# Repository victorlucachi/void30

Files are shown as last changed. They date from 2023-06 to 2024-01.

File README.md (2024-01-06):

# VOID30
*A 30% handwired ortholinear keyboard*

VOID30

The VOID30 is a 3d printed, handwired, 30% ortholinear keyboard running QMK Firmware on a Pro Micro controller.

I suggest printing the case using a 0.4 mm nozzle, supports are not needed for any of the parts.

You might want/need to use small dabs of hot glue to secure the switches in the plate depending on how well calibrated your printer is (if you're generous with it, it will add to the weight of the keyboard and it might change the feel of it).

Dont overtighten the screws as the posts could break off and the threads might get stripped.

# Handwiring guide

I've also put together a pretty visual handwiring guide for the VOID9, that you can browse over [here](https://victorlucachi.ro/journal/void9-wiring-guide/).

|  	|  	|  	|
|---|---|---|

# Bill Of Materials

* 30 x diodes ([tme.eu](https://www.tme.eu/ro/en/details/1n4148-dio/tht-universal-diodes/diotec-semiconductor/1n4148/)/[aliexpress](https://www.aliexpress.com/item/32729204179.html))
* 30 x Cherry MX style mechanical switches
* 30 x keycaps of choice
* 1 x Pro Micro ([aliexpress](https://www.aliexpress.com/item/32902569443.html))
* 24 AWG (0.2 mm2) wire
* 4 x 8mm bumpons

### Redux
* 8 x M2x3x3.5 OD heat inserts ([aliexpress](https://www.aliexpress.com/item/4000585933306.html?spm=a2g0o.order_list.order_list_main.33.21ef1802vdSNrS))
* 4 x M2x10 Allen head screws ([aliexpress](https://www.aliexpress.com/item/32966941844.html?spm=a2g0o.order_detail.order_detail_item.9.722ff19cyjrixq))
* 4 x M2x6 Countersunk screws ([aliexpress](https://www.aliexpress.com/item/32968097507.html?spm=a2g0o.order_list.order_list_main.32.21ef1802vdSNrS))

### V1
* 4 x M3x10 countersunk screws that go through the top case ([tme.eu](https://www.tme.eu/ro/en/details/b3x10_bn661/bolts/bossard/1250752/)/[aliexpress](https://www.aliexpress.com/item/32968097507.html))
* 4 x M3x10 allen head screws ([tme.eu](https://www.tme.eu/ro/en/details/m3x10_d912-a2/bolts/kraftberg/)/[aliexpress](https://www.aliexpress.com/item/32966941844.html))
* hotglue

# Pin assignment

    ROW0    ROW1    ROW2
    F6      F7      B1

    COL0    COL1    COL2    COL3    COL4    COL5    COL6    COL7    COL8    COL9
    F5      F4      B5      B4      E6      D7      C6      D4      D0      D1

# QMK Vial Fork

A QMK Vial fork can be found [here](https://github.com/victorlucachi/vial-qmk/tree/dev_void/keyboards/handwired/void30).

Most features are disabled in order for the firmware to fit on the atmega32u4 present on the Pro Micro controllers, but if you want to tinker around with different features or if you're using a different MCU you can enable/disable them to suit your own needs by editing the rules.mk file in the vial keymap folder.

The web version of Vial is available at [vial.rocks](https://vial.rocks/); it runs in supported browsers (Chrome, Edge and Opera) without requiring an installation.

VOID30 Vial

# QMK Fork

A fork containing the QMK config files can be found [here](https://github.com/victorlucachi/qmk_firmware/tree/dev_void/keyboards/handwired/void30). Edit them to suit your own needs and build the firmware following the QMK docs.

If you plan on using the VIA configurator dont forget to download the json definitions file linked in this repository.

# ZMK Config Repo

A ZMK config repo for wireless builds can be found [here](https://github.com/fidepus/ZMK-Config-Void30), thanks to [fidepus](https://github.com/victorlucachi/void30/issues/2). The firmware is configured around the [Puchi BLE](https://keycapsss.com/keyboard-parts/mcu-controller/202/puchi-ble-wireless-microcontroller-pro-micro-replacement) controller, but it can be easily adapted to a nice!nano or any other [ZMK supported hardware](https://zmk.dev/docs/hardware#composite).



This work is licensed under a [Creative Commons Attribution-NonCommercial-ShareAlike 4.0 International License](https://creativecommons.org/licenses/by-nc-sa/4.0/).

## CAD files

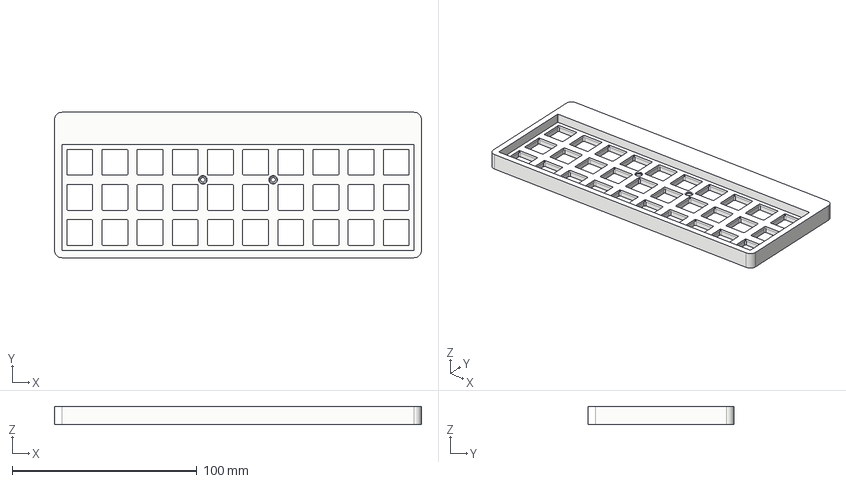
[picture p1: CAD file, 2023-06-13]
Redux/STEP/VOID30 Redux - Top - Flat.step
198.8 x 78.8 x 10.0 mm

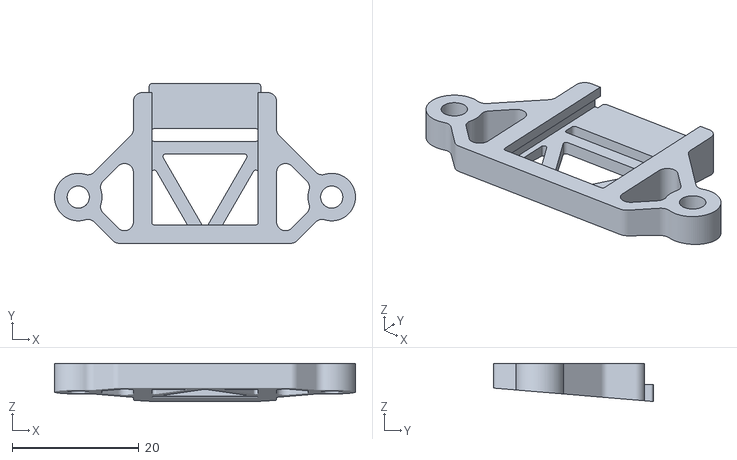
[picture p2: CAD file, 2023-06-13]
Redux/STL/Controller/21.5x18mm - Seeed Xiao - Angled.stl
47.5 x 25.2 x 6.00

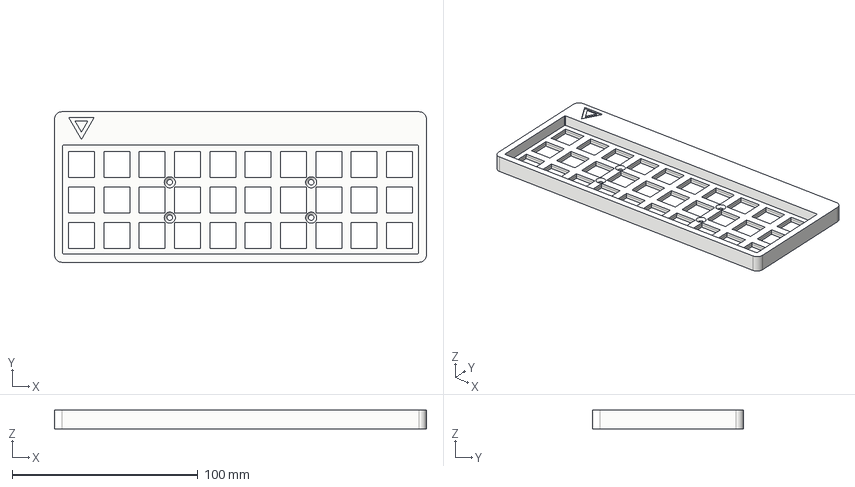
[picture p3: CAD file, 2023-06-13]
v1/STEP/VOID30 - Top.step
200.5 x 81.1 x 10.0 mm

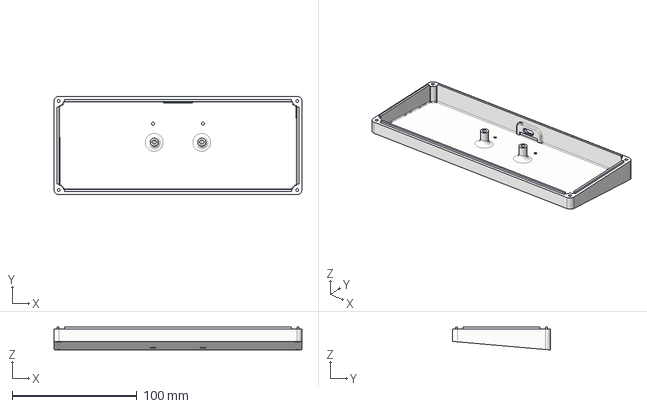
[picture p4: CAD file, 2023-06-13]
Redux/STEP/VOID30 Redux - Bottom - Angled.step
198.8 x 78.8 x 18.4 mm

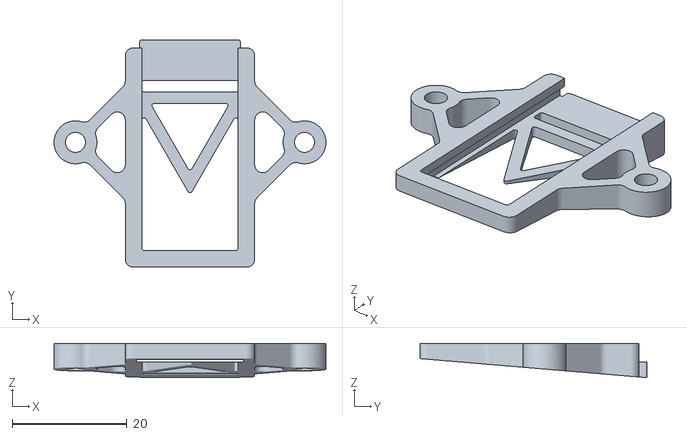
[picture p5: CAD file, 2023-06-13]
Redux/STL/Controller/36x18mm - Type C Pro Micro - Angled.stl
47.5 x 39.7 x 6.00

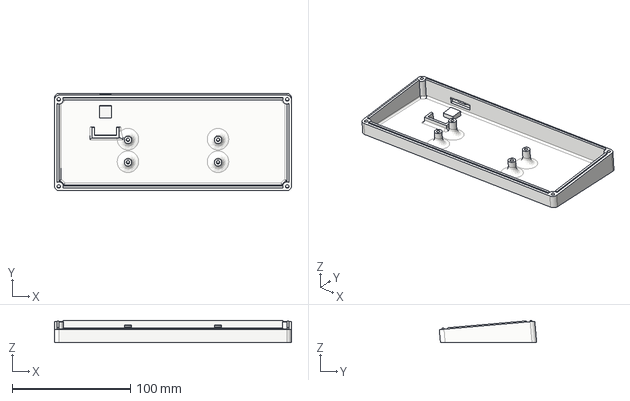
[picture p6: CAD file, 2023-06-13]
v1/STEP/VOID30 - Bottom.step
200.5 x 82.4 x 18.8 mm

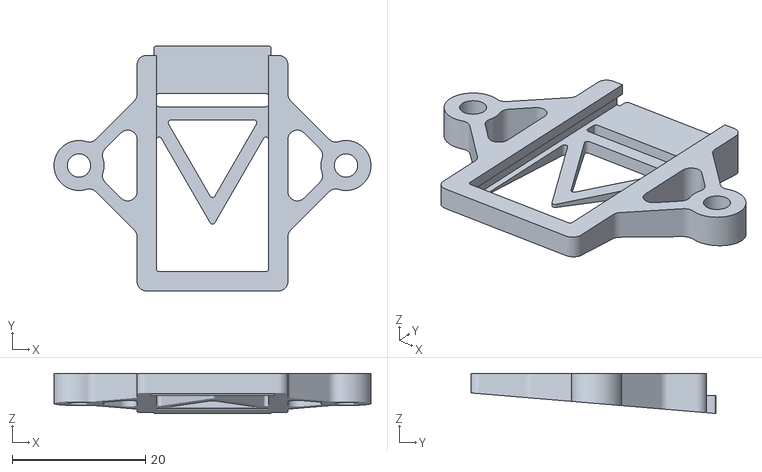
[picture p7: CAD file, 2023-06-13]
Redux/STL/Controller/33x18mm - Pro Micro - Angled.stl
47.5 x 36.7 x 6.00

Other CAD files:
v1/STEP/VOID30 - Top - No Logo.step
Redux/STL/VOID30 Redux - Bottom - Angled.stl
Redux/STL/VOID30 Redux - Top - Flat.stl
v1/STL/VOID30 - Bottom.stl
v1/STL/VOID30 - Top - No Logo.stl
v1/STL/VOID30 - Top.stl

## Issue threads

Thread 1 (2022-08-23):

Source CAD files

stevexyz, 2022-08-23:
Is possible you to publish also the source CAD file to be able to modify it?

stevexyz, 2023-07-13:
Seems completed but I was not able to find the source CAD files (just outputs for 3d printers)

victorlucachi, 2023-07-14:
> Seems completed but I was not able to find the source CAD files (just outputs for 3d printers)

yes, hello steve. step files have been uploaded, and for simple mods they are easier to edit/work with than mesh/stl. I am not publishing my f3d files, the models are easy enough to replicate from scratch, and if you have any particular questions in mind that I might be able to answer you can always drop me a line.

stevexyz, 2023-07-14:
Ciao Victor! :)

> ... if you have any particular questions in mind that I might be able to answer you can always drop me a line.

My idea was to slightly modify them to be able to create something like this: https://github.com/stevexyz/qmk_firmware/blob/master/stevexyz28custom.jpg

Closed 2023-06-13.

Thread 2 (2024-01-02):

ZMK Firmware

fidepus, 2024-01-02:
I made [ZMK](https://zmk.dev) firmware for the Keyboard, in case anybody wants to do a wireless version. This one is for the [Puchi BLE](https://keycapsss.com/keyboard-parts/mcu-controller/202/puchi-ble-wireless-microcontroller-pro-micro-replacement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) board, but should be easily adaptable for others.

[Repo](https://github.com/fidepus/ZMK-Config-Void30)

victorlucachi, 2024-01-06:
> I made [ZMK](https://zmk.dev) firmware for the Keyboard, in case anybody wants to do a wireless version. This one is for the [Puchi BLE](https://keycapsss.com/keyboard-parts/mcu-controller/202/puchi-ble-wireless-microcontroller-pro-micro-replacement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) board, but should be easily adaptable for others. Untested until my hardware arrives.
>
> [Repo](https://github.com/fidepus/ZMK-Config-Void30)

Awesome, thank you! I'll link the config repo in the readme.

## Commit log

2021-04-01 Added .step files
    [VOID30 - Bottom.step, VOID30 - Top - No Logo.step, VOID30 - Top.step]
2023-06-13 redux prep
    - restructured repo
    - added precompiled fw
    - prep for redux models
    [VOID30 - Bottom.step, VOID30 - Bottom.stl, VOID30 - Top - No Logo.step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]
2023-06-13 VOID30 Redux
    - added redux models
    - modular pro micro controller mount
    - m2 hardware
    - m2 brass inserts
    [VOID30 Redux - Bottom - Angled.step, VOID30 Redux - Bottom - Angled.stl, VOID30 Redux - Pro Micro - Angled.step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]
2023-06-13 properly export step files
    [VOID30 Redux - Bottom - Angled.step, VOID30 Redux - Pro Micro - Angled.step, VOID30 Redux - Top - Flat.step]
2023-06-13 modular controller mounts
    - added modular mounts for a couple of controllers
    [21.5x18mm - Seeed Xiao - Angled.stl, 23.5x18mm - Waveshare rp2040 zero - Angled.stl, 33x18mm - Pro Micro - Angled.stl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]
2023-07-03 removed waveshare controller mount
    [23.5x18mm - Waveshare rp2040 zero - Angled.stl]

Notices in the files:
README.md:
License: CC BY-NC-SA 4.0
